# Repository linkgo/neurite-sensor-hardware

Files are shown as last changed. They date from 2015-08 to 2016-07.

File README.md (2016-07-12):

[English](#) | [中文](#)

# Neurite Sensor

The sensor hardware based on esp8266 powered by [Neurite](https://github.com/linkgo/neurite) firmware.  
Originally we use nodemcu lua scripts until we were hardly able to work around the memory issues.

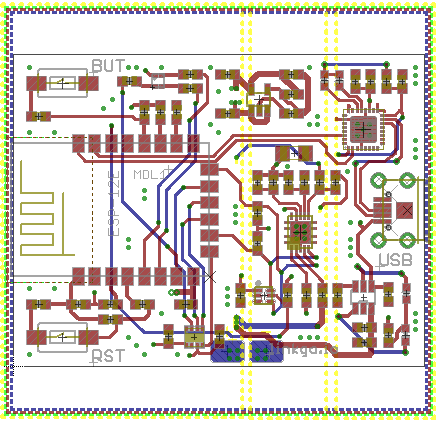
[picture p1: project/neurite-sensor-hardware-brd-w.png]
neurite-sensor-hardware-brd-w


## Demo

As a demo scenario, we put some modules in our office, collecting realtime data.  
Jump: [lab of linkgo.io](http://lab.linkgo.io)

## License

> The MIT License (MIT)
>
> Copyright (c) 2015-2016 Linkgo LLC
>
> Permission is hereby granted, free of charge, to any person obtaining a copy
> of this software and associated documentation files (the "Software"), to deal
> in the Software without restriction, including without limitation the rights
> to use, copy, modify, merge, publish, distribute, sublicense, and/or sell
> copies of the Software, and to permit persons to whom the Software is
> furnished to do so, subject to the following conditions:
>
> The above copyright notice and this permission notice shall be included in all
> copies or substantial portions of the Software.
>
> THE SOFTWARE IS PROVIDED "AS IS", WITHOUT WARRANTY OF ANY KIND, EXPRESS OR
> IMPLIED, INCLUDING BUT NOT LIMITED TO THE WARRANTIES OF MERCHANTABILITY,
> FITNESS FOR A PARTICULAR PURPOSE AND NONINFRINGEMENT. IN NO EVENT SHALL THE
> AUTHORS OR COPYRIGHT HOLDERS BE LIABLE FOR ANY CLAIM, DAMAGES OR OTHER
> LIABILITY, WHETHER IN AN ACTION OF CONTRACT, TORT OR OTHERWISE, ARISING FROM,
> OUT OF OR IN CONNECTION WITH THE SOFTWARE OR THE USE OR OTHER DEALINGS IN THE
> SOFTWARE.

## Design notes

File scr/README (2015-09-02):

README
======

Upload Scripts
--------------

1.  Flash the latest NodeMCU firmware with esptool.py, can be found here:
    https://github.com/pfalcon/esptool/blob/master/esptool.py

    $ esptool.py --port $UART_PORT write_flash 0x0 $BIN_FILE

e.g.
    $ esptool.py --port /dev/cu.usbserial-00001014 write_flash 0x0 ~/Desktop/nodemcu_float_0.9.6-dev_20150704.bin

2.  Upload scripts with nodemcu-uploader.py, from:
    https://github.com/kmpm/nodemcu-uploader.git

    $ nodemcu-uploader.py --port $UART_PORT --baud $BAUD upload $FILE

e.g.
    $ nodemcu-uploader.py --port /dev/ttyUSB0 --baud 115200 upload lsap.lua

    or uploading all the files in one shot:

    $ nodemcu-uploader.py --port /dev/ttyUSB0 --baud 115200 upload `ls *.lua` `ls http/*`

Ps:
    Alternatively, we can also use luatool.py for single file upload:
    $ luatool.py -p /dev/cu.usbserial-A503TUYM -b 115200 -f work.lua -t work.lua

Run Test
--------

    > dofile("test.lua")

Working Modes
-------------

    ACTIVE: Normal working mode that act as STA or AP.
            (e.g. exchange data with server and then sleep)

    SLEEP:  Deep sleep at most times, waking up at intervals.
            (e.g. sleep 1 min and wake up for 3 sec)

    DEBUG:  Nothing runs, except for the lua prompt itself.

    Since we are on battery all the time, we need the capability to
switch among different modes according to one single user button,
and keep the battery lasting as long as possible at the same time.

    Thus, to achieve all three states ACTIVE, SLEEP and DEBUG, we
designed this flow which can be described as:

       Boot
        |
        v
 button pressed? ---+
      Y |         N |
        v           |
 toggle flag_dsleep |
        |           |
        + <---------+
        |
        v
 flag_dsleep == false? ---+
      Y |               N |
        v                 v
     ACTIVE        button pressed? ---+
                        Y |         N |
                          v           v
                        DEBUG       SLEEP

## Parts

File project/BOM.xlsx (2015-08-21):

No. | Part P/N | Description | Q'ty | Manufacturer | Manufacture P/N | ROHS
PCB SMT
1 | R25 | 0.02 OHM-1/2W-1%(1206) | 1 | Yageo | PF1206FRF070R02L | Y
2 | C1, C2, C4, C11, C12, C13, C14, C15, C16, C17, C18 | 0.1 UF-25V(+80/-20%)(0603) | 11 | Yageo | CC0603KRX7R7BB104 | Y
3 | LED5 | RGB full color LED(20mA)(1615) | 1 | Harvatek | HT19-2331BGRC | Y
4 | R11 | 0 OHM-1/10W-1%(0603) | 1 | Panasonic | ERJ-3EKF0000V | Y
5 | R3 | 2K OHM-1/10W-1%(0603) | 1 | Panasonic | ERJ-3EKF2001V | Y
6 | R6 | 100 OHM-1/10W-1%(0603) | 1 | Panasonic | ERJ-3EKF1000V | Y
7 | R4, R7, R8, R9, R10, R17, R18, R23, R24 | 10K OHM-1/10W-1%(0603) | 9 | Panasonic | ERJ-3EKF1002V | Y
8 | R5, R14, R15, R16, R19, R20, R21 | 1K OHM-1/10W-1%(0603)0603 | 7 | Panasonic | ERJ-3EKF1001V | Y
9 | C5, C8 | 1UF-10V(+80/-20%)(0603) | 2 | Yageo | CC0603KRX7R7BB105 | Y
10 | C7 | 2.2UF-10V(+80/-20%)(0603) | 1 | Yageo | CC0603KRX5R6BB225 | Y
11 | C3, C9, C10 | 4.7UF-10V(+80/-20%)(0603) | 3 | Yageo | CC0603KRX5R7BB475 | Y
12 | R12, R13 | 470 OHM-1/10W-1%(0603)0603 | 2 | Panasonic | ERJ-3EKF4700V | Y
13 | U2 | DIGITAL HUMIDITY, PRESSURE AND TEMPERATURE SENSOR | 1 | BOSCH | BME280 | Y
14 | U4 | Li-Ion AND Li-Pol BATTERY GAS GAUGE IC | 1 | Texas Instruments | BQ27210DRKR | Y
15 | S1, S2 | Tract switch,J-bent terminal,2-SMD | 2 | IL SWITCH | 1181U | Y
16 | LED1 | Chiped LED RED(0603) | 1 | Kingbright | KP-1608SRC-PRV | Y
17 | U3 | USB Interface IC USB to Serial UART Enhanced IC (QFN-32) | 1 | FT232RQ | FT232RQ-REEL | Y
18 | LED2, LED3, LED4 | Chiped LED GREEN(0603) | 3 | Kingbright | KPT-1608VGC-A | Y
19 | U5 | LDO Voltage Regulators 500mA Low Noise(SOT-23-5) | 1 | Exar | SPX3819M5-L-3-3 | Y
20 | U6 | TP4057 Lithium Battery Cell Charging IC(SOT-23-6) | 1 | Top Power | TP4057 | Y
21 | U1 | Light to Digital Converters Light to Digital Sensor(DFN-6) | 1 | TAOS | TSL2561FN | Y
22 | X1 | USB-MICROB | 1 | USB-MICROB | USB Connectors | Y

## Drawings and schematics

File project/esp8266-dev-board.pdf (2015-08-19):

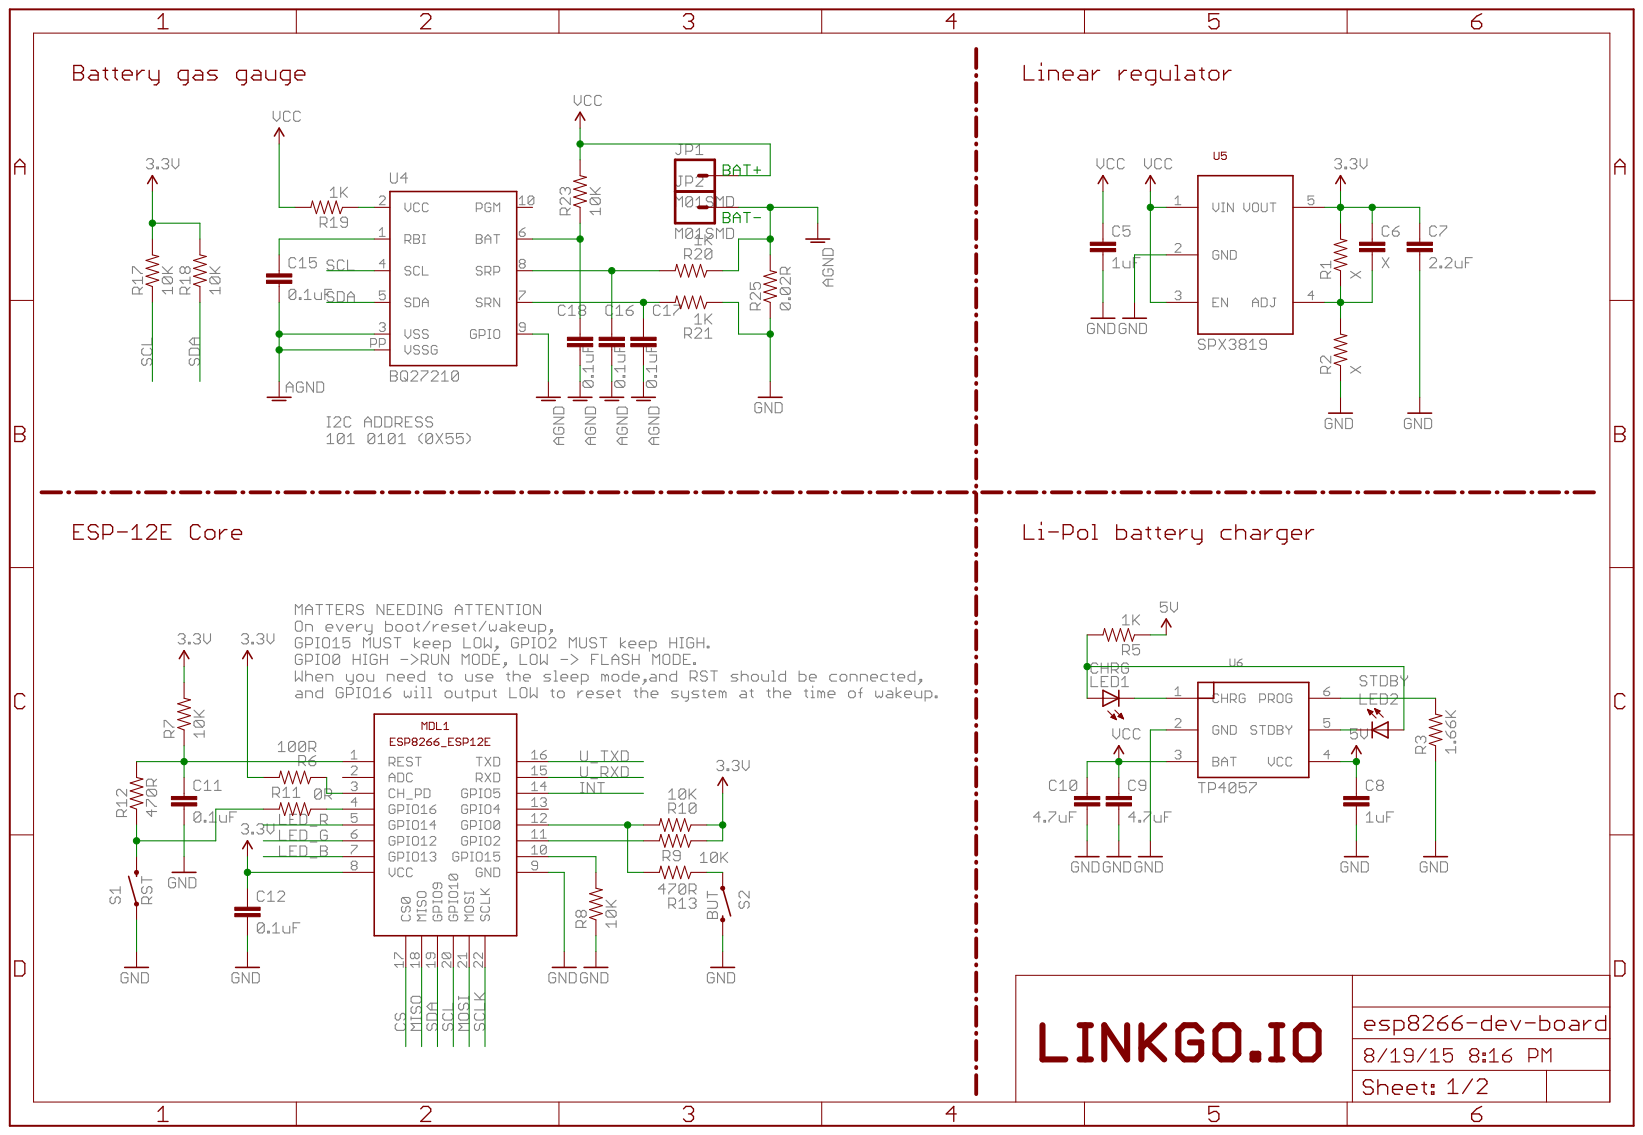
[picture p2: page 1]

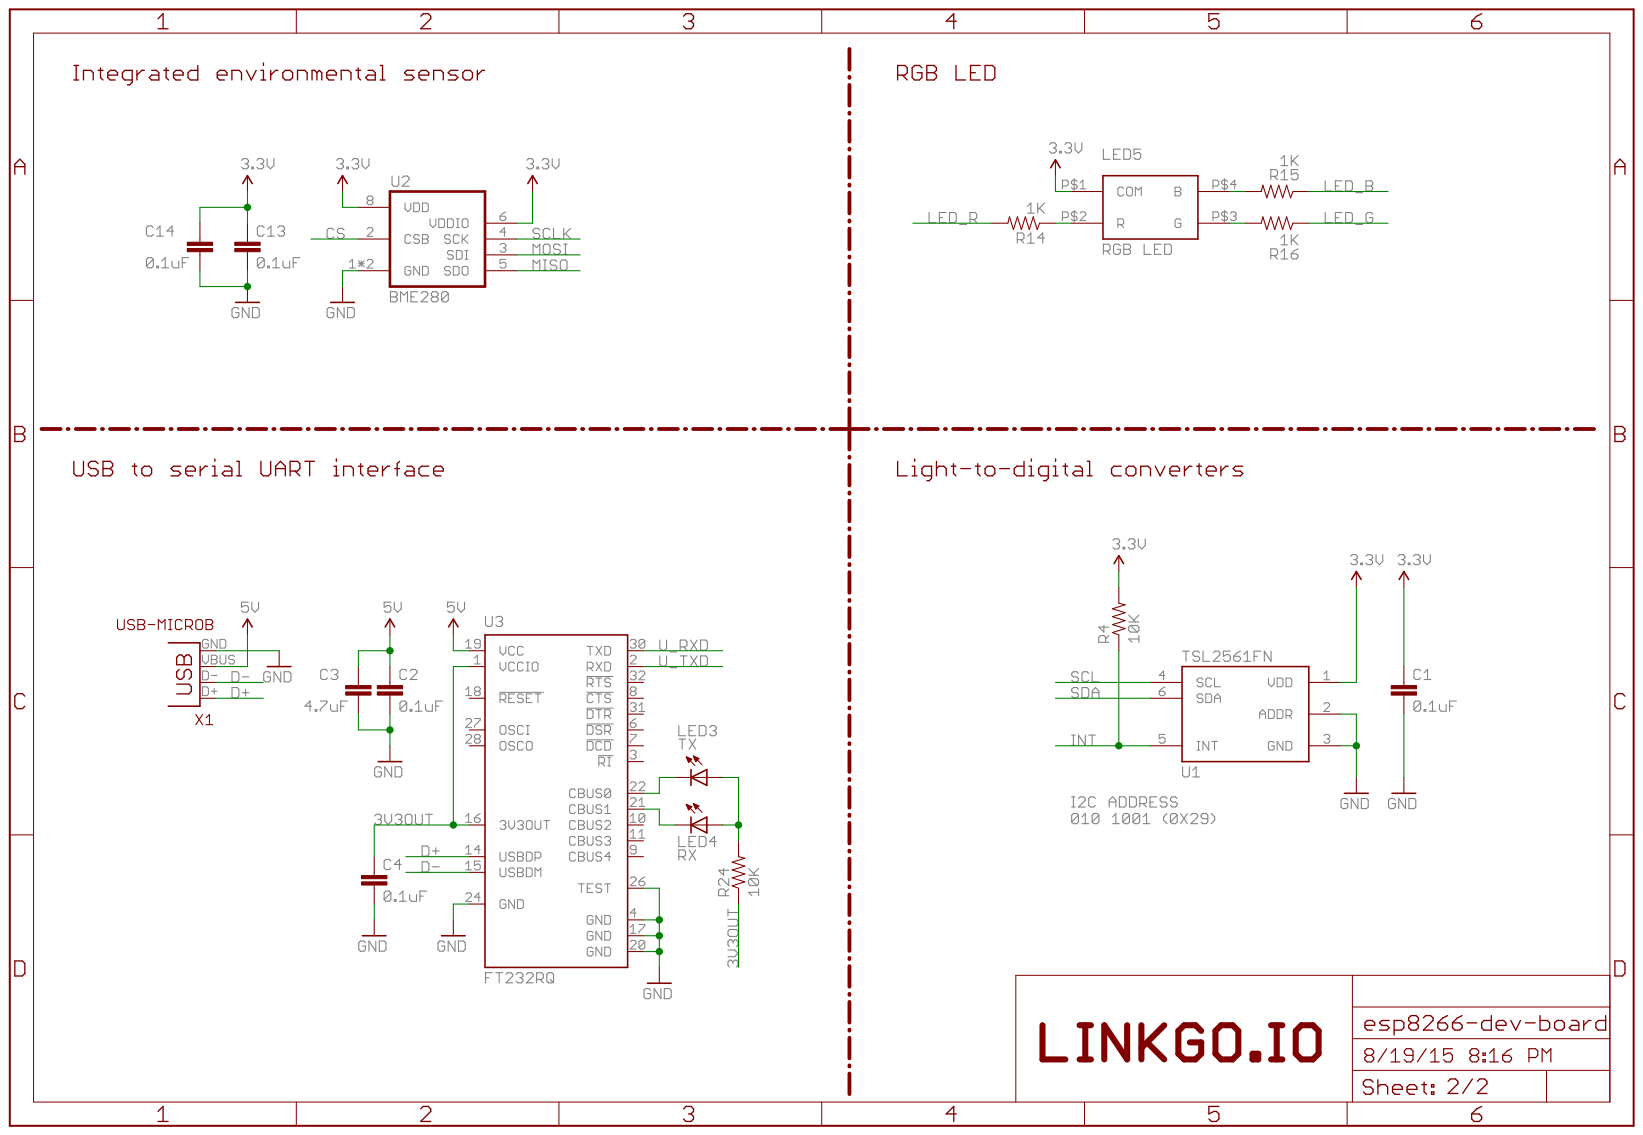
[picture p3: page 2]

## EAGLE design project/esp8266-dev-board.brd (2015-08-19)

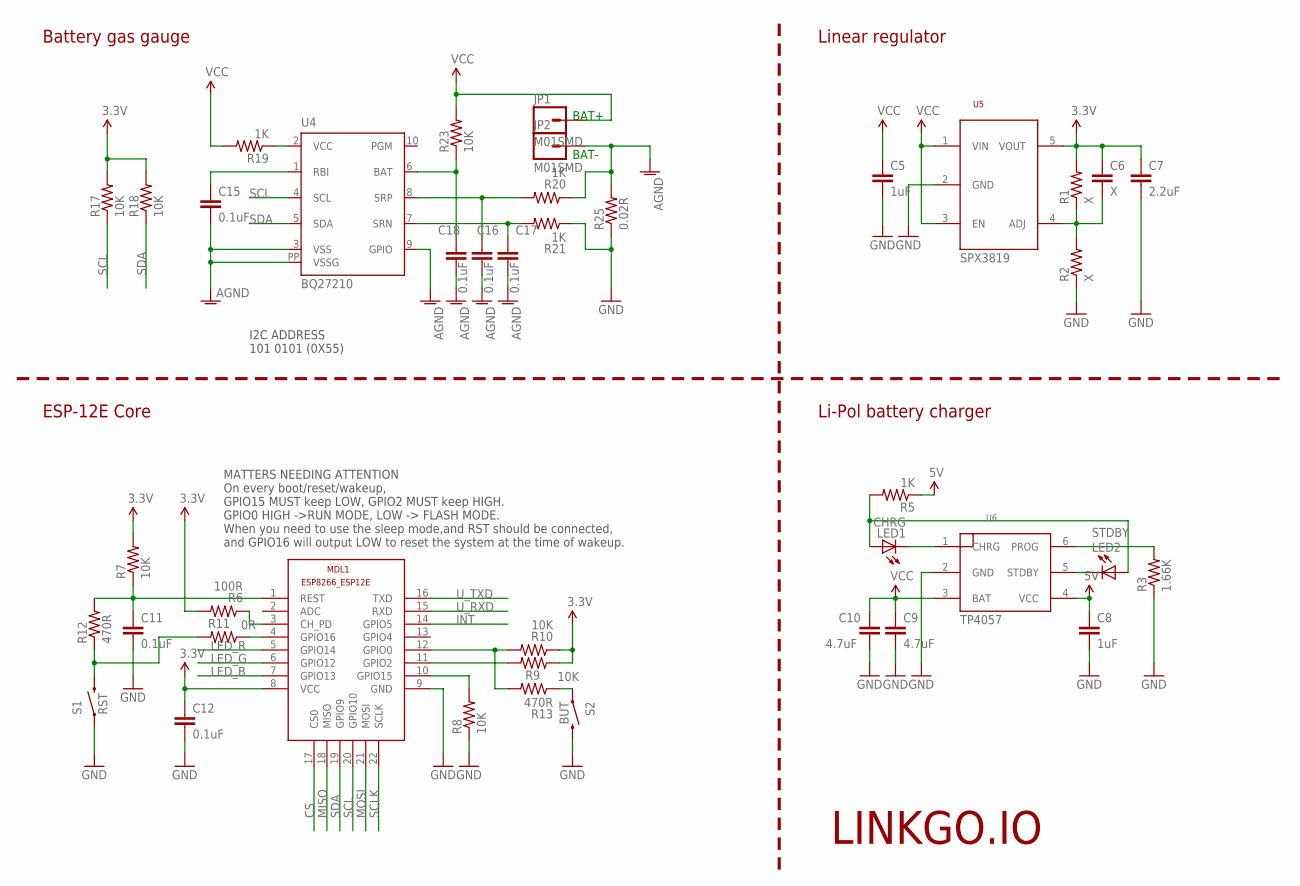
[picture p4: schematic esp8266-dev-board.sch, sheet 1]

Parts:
C5, C8: 1uF; 0603-CAP
C6: X; 0603-CAP
C7: 2.2uF; 0603-CAP
C9, C10: 4.7uF; 0603-CAP
C11, C12, C15, C16, C17, C18: 0.1uF; 0603-CAP
JP1, JP2: M01SMD; LUXEON-PAD
LED1: CHRG; LED-0603
LED2: STDBY; LED-0603
MDL1: ESP8266-12EESP8266-ESP12E; ESP8266-ESP12E
R1, R2: X; 0603-RES
R3: 1.66K; 0603-RES
R5, R19, R20, R21: 1K; 0603-RES
R6: 100R; 0603-RES
R7, R8, R9, R10, R17, R18, R23: 10K; 0603-RES
R11: 0R; 0603-RES
R12, R13: 470R; 0603-RES
R25: 0.02R; 1206
S1: RST; TACTILE-SWITCH-1101NE
S2: BUT; TACTILE-SWITCH-1101NE
U4: BQ27210; DRK_S-PDSO-N10
U5: SPX3819M5-ADJ; SOT23-5
U6: TP4057; SOT23-6

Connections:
3.3V: C6.1, C7.1, C12.1, MDL1.8 (VCC), R1.2, R6.2, R7.2, R9.1, R10.1, R17.2, R18.2, U5.5 (VOUT); also elsewhere on the board
5V: C8.1, R5.1, U6.4 (VCC); also elsewhere on the board
AGND: C15.2, C16.2, C17.2, C18.2, JP2.P$1, R20.1, R25.2, U4.3 (VSS), U4.9 (GPIO), U4.PP (VSSG)
CS: MDL1.17 (CS0); also elsewhere on the board
GND: C5.2, C7.2, C8.2, C9.2, C10.2, C11.2, C12.2, MDL1.9 (GND), R2.1, R3.1, R8.1, R21.1, R25.1, S1.P$1 (1), S2.P$2 (2), U5.2 (GND), U6.2 (GND); also elsewhere on the board
INT: MDL1.14 (GPIO5); also elsewhere on the board
LED_B: MDL1.7 (GPIO13); also elsewhere on the board
LED_G: MDL1.6 (GPIO12); also elsewhere on the board
LED_R: MDL1.5 (GPIO14); also elsewhere on the board
MISO: MDL1.18 (MISO); also elsewhere on the board
MOSI: MDL1.21 (MOSI); also elsewhere on the board
unnamed: C6.2, R1.1, R2.2, U5.4 (ADJ)
unnamed: MDL1.10 (GPIO15), R8.2
unnamed: MDL1.12 (GPIO0), R10.2, R13.2
unnamed: LED1.A, LED2.A, R5.2
unnamed: C11.1, MDL1.1 (REST), R7.1, R12.2
unnamed: LED1.C, U6.1 (CHRG)
unnamed: LED2.C, U6.5 (STDBY)
unnamed: R3.2, U6.6 (PROG)
unnamed: MDL1.3 (CH_PD), R6.1
unnamed: MDL1.11 (GPIO2), R9.2
unnamed: MDL1.4 (GPIO16), R11.1
unnamed: R11.2, R12.1, S1.P$2 (2)
unnamed: R13.1, S2.P$1 (1)
unnamed: C15.1, U4.1 (RBI)
unnamed: R19.1, U4.2 (VCC)
unnamed: C17.1, R21.2, U4.7 (SRN)
unnamed: C16.1, R20.2, U4.8 (SRP)
unnamed: C18.1, R23.1, U4.6 (BAT)
PP: U4.PP@1 (PP), U4.PP@2 (PP), U4.PP@3 (PP), U4.PP@4 (PP), U4.PP@5 (PP), U4.PP@6 (PP), U4.PP@7 (PP), U4.PP@8 (PP), U4.PP@9 (PP), U4.PP@10 (PP)
SCL: MDL1.20 (GPIO10), R17.1, U4.4 (SCL); also elsewhere on the board
SCLK: MDL1.22 (SCLK); also elsewhere on the board
SDA: MDL1.19 (GPIO9), R18.1, U4.5 (SDA); also elsewhere on the board
U_RXD: MDL1.15 (RXD); also elsewhere on the board
U_TXD: MDL1.16 (TXD); also elsewhere on the board
VCC: C5.1, C9.1, C10.1, JP1.P$1, R19.2, R23.2, U5.1 (VIN), U5.3 (EN), U6.3 (BAT)

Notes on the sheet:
MATTERS NEEDING ATTENTION On every boot/reset/wakeup, GPIO15 MUST keep LOW, GPIO2 MUST keep HIGH. GPIO0 HIGH ->RUN MODE, LOW -> FLASH MODE. When you need to use the sleep mode,and RST should be connected, and GPIO16 will output LOW to reset the system at the time of wakeup.
BAT+
BAT-
Battery gas gauge
Linear regulator
Li-Pol battery charger
ESP-12E Core
I2C ADDRESS 101 0101 (0X55)
LINKGO.IO
SPX3819
TP4057

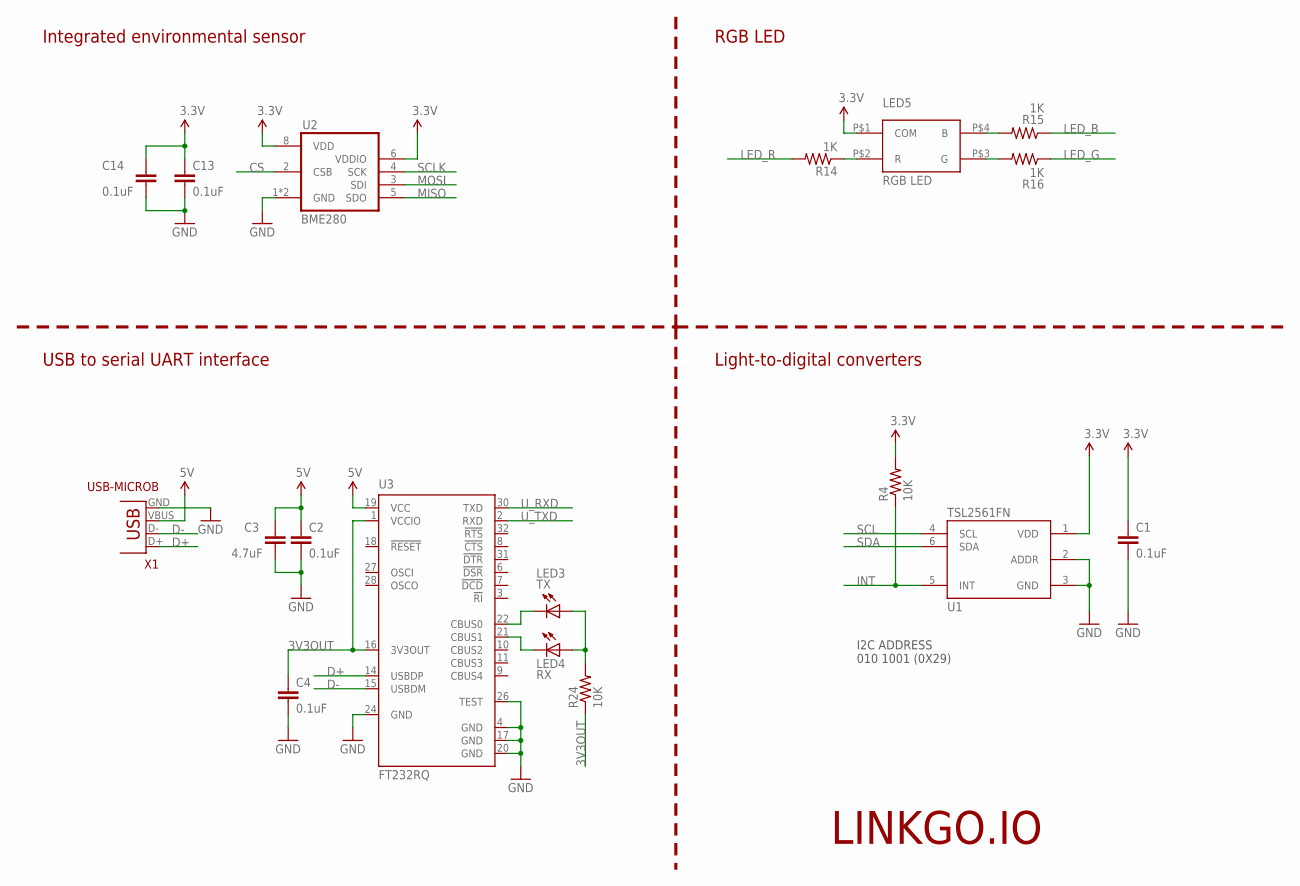
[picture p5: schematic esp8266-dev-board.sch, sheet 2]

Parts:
C1, C2, C4, C13, C14: 0.1uF; 0603-CAP
C3: 4.7uF; 0603-CAP
LED3: TX; LED-0603
LED4: RX; LED-0603
LED5: 0603RGB
R4, R24: 10K; 0603-RES
R14, R15, R16: 1K; 0603-RES
U1: TSL2561FN; FN-6
U2: BME280
U3: FT232RQ; QFN32
X1: USB-MICROB

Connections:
3.3V: C1.1, C13.1, C14.1, LED5.P$1 (COM), R4.2, U1.1 (VDD), U2.6 (VDDIO), U2.8 (VDD); also elsewhere on the board
3V3OUT: C4.1, R24.1, U3.1 (VCCIO), U3.16 (3V3OUT)
5V: C2.1, C3.1, U3.19 (VCC), X1.VBUS; also elsewhere on the board
CS: U2.2 (CSB); also elsewhere on the board
D+: U3.14 (USBDP), X1.D+
D-: U3.15 (USBDM), X1.D-
GND: C1.2, C2.2, C3.2, C4.2, C13.2, C14.2, U1.2 (ADDR), U1.3 (GND), U2.1 (GND), U2.7 (GND), U3.4 (GND), U3.17 (GND), U3.20 (GND), U3.24 (GND), U3.26 (TEST), X1.GND; also elsewhere on the board
INT: R4.1, U1.5 (INT); also elsewhere on the board
LED_B: R15.1; also elsewhere on the board
LED_G: R16.1; also elsewhere on the board
LED_R: R14.2; also elsewhere on the board
MISO: U2.5 (SDO); also elsewhere on the board
MOSI: U2.3 (SDI); also elsewhere on the board
unnamed: LED3.C, U3.22 (CBUS0)
unnamed: LED4.C, U3.21 (CBUS1)
unnamed: LED5.P$2 (R), R14.1
unnamed: LED5.P$4 (B), R15.2
unnamed: LED5.P$3 (G), R16.2
unnamed: LED3.A, LED4.A, R24.2
SCL: U1.4 (SCL); also elsewhere on the board
SCLK: U2.4 (SCK); also elsewhere on the board
SDA: U1.6 (SDA); also elsewhere on the board
U_RXD: U3.30 (TXD); also elsewhere on the board
U_TXD: U3.2 (RXD); also elsewhere on the board

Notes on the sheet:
I2C ADDRESS 010 1001 (0X29)
RGB LED
Integrated environmental sensor
USB to serial UART interface
Light-to-digital converters
LINKGO.IO
LED5

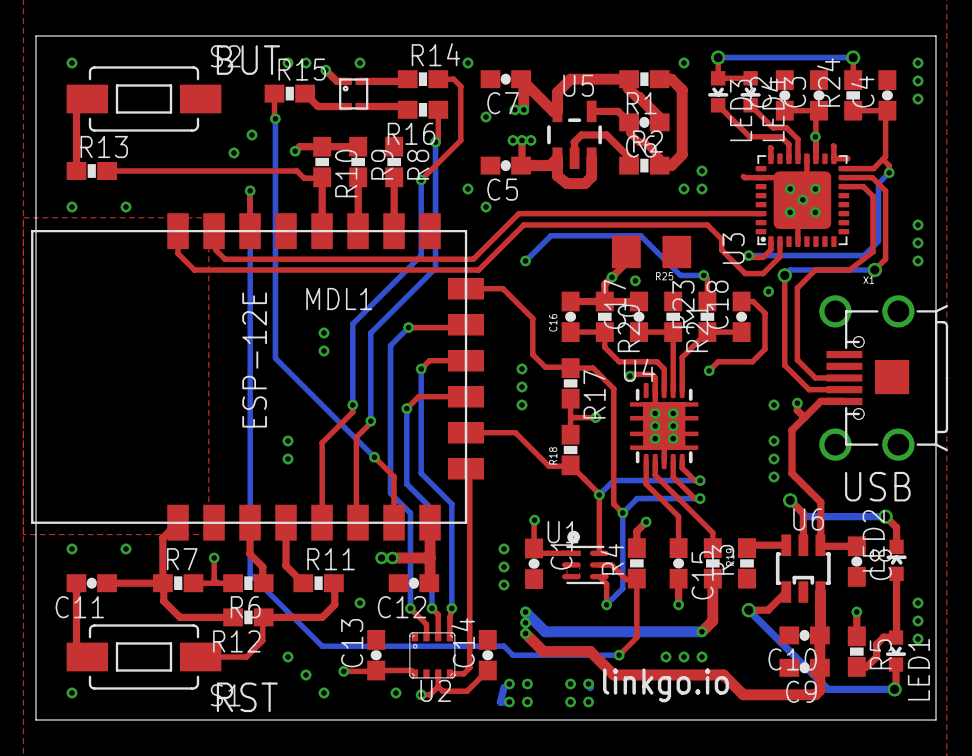
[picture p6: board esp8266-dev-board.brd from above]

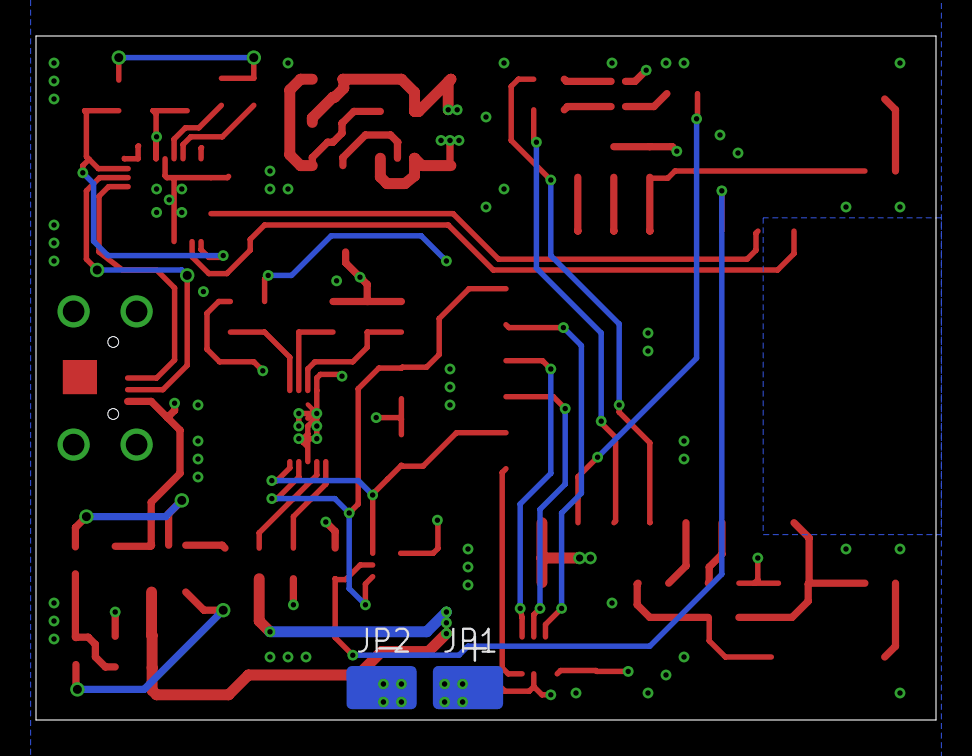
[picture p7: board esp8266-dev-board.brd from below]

Board: 4 copper layers, 50.0 x 38.0 mm, 59 parts (2 on the bottom side), 45 nets.

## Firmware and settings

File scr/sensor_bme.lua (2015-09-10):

print("sensor job: bme")

local dig_1 = 0
local dig_2 = 0
local dig_3 = 0
local dig_4 = 0
local dig_5 = 0
local dig_6 = 0
local dig_7 = 0
local dig_8 = 0
local dig_9 = 0
local var1 = 0
local var2 = 0

writeRegister(0x76, 0xf2, 0x03)
writeRegister(0x76, 0xf4, 0x3f)

-- temperature
local adc_T = bit.bor(bit.lshift(readRegister(0x76, 0xfa), 12), bit.lshift(readRegister(0x76, 0xfb), 4), bit.rshift(readRegister(0x76, 0xfc), 4))
local dig_1 = bit.bor(readRegister(0x76, 0x88), bit.lshift(readRegister(0x76, 0x89), 8))
local dig_2 = bit.bor(readRegister(0x76, 0x8a), bit.lshift(readRegister(0x76, 0x8b), 8))
local dig_3 = bit.bor(readRegister(0x76, 0x8c), bit.lshift(readRegister(0x76, 0x8d), 8))
var1 = bit.rshift(((bit.rshift(adc_T, 3) - bit.lshift(dig_1, 1)) * dig_2), 11)
var2 = bit.rshift((bit.rshift(((bit.rshift(adc_T, 4) - dig_1) * (bit.rshift(adc_T, 4) - dig_1)), 12) * dig_3), 14)
local t_fine = var1 + var2
bme280_T = bit.rshift((t_fine * 5 + 128), 8) / 100

-- pressure
local dig_1 = bit.bor(readRegister(0x76, 0x8e), bit.lshift(readRegister(0x76, 0x8f), 8))
local dig_2 = bit.bor(readRegister(0x76, 0x90), bit.lshift(readRegister(0x76, 0x91), 8))
local dig_3 = bit.bor(readRegister(0x76, 0x92), bit.lshift(readRegister(0x76, 0x93), 8))
local dig_4 = bit.bor(readRegister(0x76, 0x94), bit.lshift(readRegister(0x76, 0x95), 8))
local dig_5 = bit.bor(readRegister(0x76, 0x96), bit.lshift(readRegister(0x76, 0x97), 8))
local dig_6 = bit.bor(readRegister(0x76, 0x98), bit.lshift(readRegister(0x76, 0x99), 8))
local dig_7 = bit.bor(readRegister(0x76, 0x9a), bit.lshift(readRegister(0x76, 0x9b), 8))
local dig_8 = bit.bor(readRegister(0x76, 0x9c), bit.lshift(readRegister(0x76, 0x9d), 8))
local dig_9 = bit.bor(readRegister(0x76, 0x9e), bit.lshift(readRegister(0x76, 0x9f), 8))
local adc_P = bit.bor(bit.lshift(readRegister(0x76, 0xf7), 12), bit.lshift(readRegister(0x76, 0xf8), 4), bit.rshift(readRegister(0x76, 0xf9), 4))
var1 = t_fine - 128000
var2 = var1 * var1 * dig_6
var2 = var2 + bit.lshift(var1 * dig_5, 17)
var2 = var2 + bit.lshift(dig_4, 35)
var1 = bit.rshift(var1 * var1 * dig_3, 8) + bit.lshift(var1 * dig_2, 12)
var1 = (bit.lshift(1, 47) + var1) * bit.rshift(dig_1, 33)
if var1 == 0 then
	bme280_P = 0
else
	local p = 1048576 - adc_P
	p = ((bit.lshift(p, 31) - var2) * 3125) / var1;
	var1 = bit.lshift(dig_9 * bit.rshift(p, 13) * bit.rshift(p, 13), 25);
	var2 = bit.rshift(dig_8 * p, 19)
	p = bit.rshift(p + var1 + var2, 8) + bit.lshift(dig_7, 4)
	bme280_P = p / 256
end

-- humidity
local adc_H = bit.bor(bit.lshift(readRegister(0x76, 0xfd), 8), readRegister(0x76, 0xfe))
local dig_1 = readRegister(0x76, 0xa1)
local dig_2 = bit.bor(readRegister(0x76, 0xe1), bit.lshift(readRegister(0x76, 0xe2), 8))
local dig_3 = readRegister(0x76, 0xe3)
local dig_4 = bit.bor(bit.lshift(readRegister(0x76, 0xe4), 4), bit.band(readRegister(0x76, 0xe5), 0x0f))
local dig_5 = bit.bor(bit.rshift(readRegister(0x76, 0xe5), 4), bit.lshift(readRegister(0x76, 0xe6), 4))
local dig_6 = readRegister(0x76, 0xe7)
local v_x1_u32r = t_fine - 76800
v_x1_u32r = bit.rshift(bit.lshift(adc_H, 14) - bit.lshift(dig_4, 20) - dig_5 * v_x1_u32r + 16384, 15) * bit.rshift(bit.rshift(v_x1_u32r * bit.rshift(dig_6, 10) * (bit.rshift(v_x1_u32r * dig_3, 11) + 32768), 10) + 2097152 * dig_2 + 8192, 14)
v_x1_u32r = v_x1_u32r - bit.rshift(bit.rshift(bit.rshift(v_x1_u32r, 15) * bit.rshift(v_x1_u32r, 15), 7) * dig_1, 4)
if v_x1_u32r < 0 then v_x1_u32r = 0 end
if v_x1_u32r > 419430400 then v_x1_u32r = 419430400 end
bme280_H = bit.rshift(v_x1_u32r, 12) / 1024.0

writeRegister(0x76, 0xf2, 0x00)
writeRegister(0x76, 0xf4, 0x00)

file.remove("bme.mqtt")
file.open("bme.mqtt", "w")
file.write(bme280_T.." "..bme280_P.." "..bme280_H)
file.flush()
file.close()

print("T P H: "..bme280_T.." "..bme280_P.." "..bme280_H)

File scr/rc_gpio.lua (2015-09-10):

print("# config gpio")

io_ledb = 7
pwm.setup(io_ledb, 100, 512)
pwm.start(io_ledb)
function led(duty)
	pwm.setduty(io_ledb, duty)
end

io_but = 3
gpio.mode(io_but, gpio.INPUT)

print("io_ledb: "..io_ledb)
print("io_but: "..io_but)

-- check button status
flag_dsleep = false

local r = 0
print("check button in 0.5s, sleep/active?")
led(512)
tmr.delay(500000)
led(1023)
r = gpio.read(io_but)

if file.open("config_boot.lc") then
	file.close("config_boot.lc")
	dofile("config_boot.lc")
end

file.remove("config_boot.lua")
file.remove("config_boot.lc")
file.open("config_boot.lua", "w")
if r == 1 then
	print("no button press, dsleep: "..tostring(flag_dsleep))
else
	flag_dsleep = not flag_dsleep
	print("button presssed, dsleep: "..tostring(flag_dsleep))
end
file.writeline('flag_dsleep = '..tostring(flag_dsleep))
file.close()
node.compile("config_boot.lua")

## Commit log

2015-08-19 init commit.
    [esp8266-dev-board.brd, esp8266-dev-board.sch]
2015-08-21 Add BOM for the project.
    [BOM.xlsx]
2015-08-25 update rgb led test, init wifi mode to station
2015-08-26 apply scripts for rework version
    assignment:
    gpio14 -- sda
    gpio12 -- scl
    [rc_gpio.lua, rc_i2c.lua]
2015-08-27 add button function
2015-08-27 interrupt sucks for button, use tmr, elegantly...
    we can support short press, long press, long long press....
    [rc_gpio.lua]
2015-08-27 if but.lua started in rc, any button press crashes...
2015-08-28 update i2c pin assignment
2015-08-29 add lower power mode
2015-08-29 config pwm for led
2015-08-30 add breathing led representing alive working
2015-08-30 do not touch led in but.lua
2015-08-31 lower cpu usage on led
2015-08-31 clean up code, compile source to save mem
    1. remove the fat httpserver things, use another method, in:
    rc_wifi.lua
    run_config.lua
    2. remove unused code
    3. replace html file with a new one
    [rc_gpio.lua, rc_i2c.lua]
2015-08-31 softap wifi config works
    now we can use softap mode to config ssid and password,
    then restart and switch to station mode for normal job.
2015-08-31 support boot mode switching
    press BUT after reset until led on/off cycle finished,
    to switch between boot modes below:
    1. flag_dsleep == true: enter deep sleep without doing anything
    2. flag_dsleep == false: start normal job, then go to deep sleep
    [rc_gpio.lua]
2015-08-31 unify led control, use pwm
2015-08-31 remove trivial print
2015-08-31 reduce prints
2015-09-02 add DEBUG mode, in addition to ACTIVE and SLEEP.
    Sometimes we need nothing other than the lua prompt, especiall to debug.
    Since we are on battery all the time, we need to switch among different
    modes according to one single user button, and keep the battery last
    long at the same time.
    Thus, to achieve all three states ACTIVE, SLEEP and DEBUG, we
    designed this flow which can be described as:
    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
2015-09-07 a bunch of update for mqtt automation
    current load: sleep 60s and wake up a bit of time to publish data.
2015-09-10 prints can't be in tmr callback, but is ok now
2015-09-10 update sensor jobs
2015-09-11 make use of async for sensor job while connecting
2015-09-11 if fail to connect, sleep and try at next wake up
    We have this change in order to avoid the case that if the wifi
    signal is not good, esp fails to connect then act as softap forever.
    If we would like to change the ssid information, just keep pressing
    the button when goes into active mode after boot up.

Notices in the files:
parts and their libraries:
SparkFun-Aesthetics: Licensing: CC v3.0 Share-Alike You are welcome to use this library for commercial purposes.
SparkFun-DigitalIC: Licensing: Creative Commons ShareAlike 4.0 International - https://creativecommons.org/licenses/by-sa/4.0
